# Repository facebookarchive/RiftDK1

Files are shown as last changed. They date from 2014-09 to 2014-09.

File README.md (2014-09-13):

Oculus Rift Development Kit 1
=======

Firmware, Schematics, and Mechanicals for the Oculus Rift Development Kit 1.

Firmware
--------

The Tracker firmware uses the CooCox CoIDE for development along with 
the gcc-arm-embedded toolchain.

The ST-Link/V2 is the cheapest way to load firmware onto a Tracker
board, though any SWD compatible programmer should work.  You can follow these steps
to set up a build environment and load firmware onto the board:

1. Install ST-Link drivers if you haven't: http://www.st.com/web/en/catalog/tools/PF258167
2. Install CoCenter: http://www.coocox.org/CooCox_CoIDE.htm
3. Through CoCenter, install CooCox and CoFlash
4. Install gcc-arm-embedded: https://launchpad.net/gcc-arm-embedded/+download
5. Set up gcc-arm-embedded in CooCox: http://www.coocox.org/CoIDE/Compiler_Settings.html
6. Clone our RiftDK1 repository to C:\CooCox\CoIDE\workspace
7. Open the Tracker.coproj
8. Build
9. Plug the ST-Link into the board's 10 pin SWD header.
10. Plug in USB to power the board.
12. Download code to Flash 
13. Enjoy!

Note that the USB Product ID is set to 0x0001, which matches the production
version of the Tracker.  If you modify the firmware in a way that
changes the USB interface, please change the Product ID to 0x0000.

Mechanical
----------

The Mechanical folder contains STEP files of the Rift DK1 housing, control box, and case.

Schematics
----------

The Schematics folder contains a pdf of the schematic, as well as Altium Designer files
of the schematic and board layout.

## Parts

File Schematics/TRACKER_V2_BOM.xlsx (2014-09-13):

Comment | Part Number | Description | Designator | Manufacturer | Quantity | Notes
4-103240-0-04 | 4-103240-0-04 | CONNECTOR, HEADER, 2X4, 0.1" PITCH | J4 | TE CONNECTIVITY | 1 | DNP
CSTCE8M00G55-R0 | CSTCE8M00G55-R0 | CERAMIC RESONATOR, 8MHz, +/-0.2%, 33pF, SMD | Y1 | MURATA ELECTRONICS | 1
22 ohm | ERJ-2RKF22R0X | RES, 22 OHM, 1/10W, ±1%, 0402 | R1, R2, R3, R4, R5, R7, R8, R9 | PANASONIC | 8
10K | ERJ-2RKF1002X | RES, 10K OHM, 1/10W, ±1%, 0402 | R6 | PANASONIC | 1
1.5K | ERJ-2RKF1501X | RES, 1.5K OHM, 1/10W, ±1%, 0402 | R10 | PANASONIC | 1
1uF | GRM155R61A105KE15D | CAP, CERAMIC, 1uF, ±10%, 10V, X5R, 0402 | C15 | MURATA ELECTRONICS | 1
0.1uF | GRM155R71C104KA88D | CAP, CERAMIC, 0.1uF, ±10%, 16V, X7R, 0402 | C5, C8, C11, C12, C13, C14, C16, C19, C21, C23 | MURATA ELECTRONICS | 10
0.22uF | GRM155R71C224KA12D | CAP, CERAMIC, 0.22uF, ±10%, 16V, X7R, 0402 | C17 | MURATA ELECTRONICS | 1
2200pF | GRM155R71H222KA01D | CAP, CERAMIC, 2200pF, ±10%, 50V, X7R, 0402 | C1, C2, C6, C7, C18 | MURATA ELECTRONICS | 5
10uF | GRM188R60J106ME47D | CAP, CERAMIC, 10uF, ±20%, 6.3V, X5R, 0603 | C3, C4, C9, C10, C20 | MURATA ELECTRONICS | 5
4.7uF | GRM188R60J475KE19D | CAP, CERAMIC, 4.7uF, ±10%, 6.3V, X5R, 0603 | C22 | MURATA ELECTRONICS | 1
GRPB052VWQP-RC | GRPB052VWQP-RC | CONNECTOR, 10 POS, ARM CORTEX SWD HEADER | J3 | SULLINS CONNECTOR | 1 | DNP
HMC5983 | HMC5983-TR | IC, MEMS 3 AXIS MAGNETOMETER | U4 | HONEYWELL | 1
LP5900SD-3.3 | LP5900SD-3.3/NOPB | IC, LINEAR REGULATOR, 3.3V, 150MA, ULTRA LOW NOISE | U2 | NATIONAL SEMICONDUCTOR | 1
MMZ1005S601C | MMZ1005S601C | FERRITE CHIP BEAD, 600 OHM @ 100MHz, 300mA, 0402 | L1, L2, L3, L4 | TDK CORPORATION | 4
MPU-6000 | MPU-6000 | IC, MEMS 3 AXIS GYROSCOPE AND 3 AXIS ACCELEROMETER | U3 | INVENSENSE | 1
STM32F103C8T6 | STM32F103C8T6 | IC, STM32 MICROCONTROLLER, ARM CORTEX M3 | U1 | ST MICROELECTRONICS | 1
USB_HEADER | TBD | CONNECTOR, HEADER, 4 POS | J1 | TBD | 1
ZX62-B-5PA(11) | ZX62-B-5PA(11) | CONNECTOR, USB MICRO B, R/A, SMD | J2 | HIROSE | 1 | DNP

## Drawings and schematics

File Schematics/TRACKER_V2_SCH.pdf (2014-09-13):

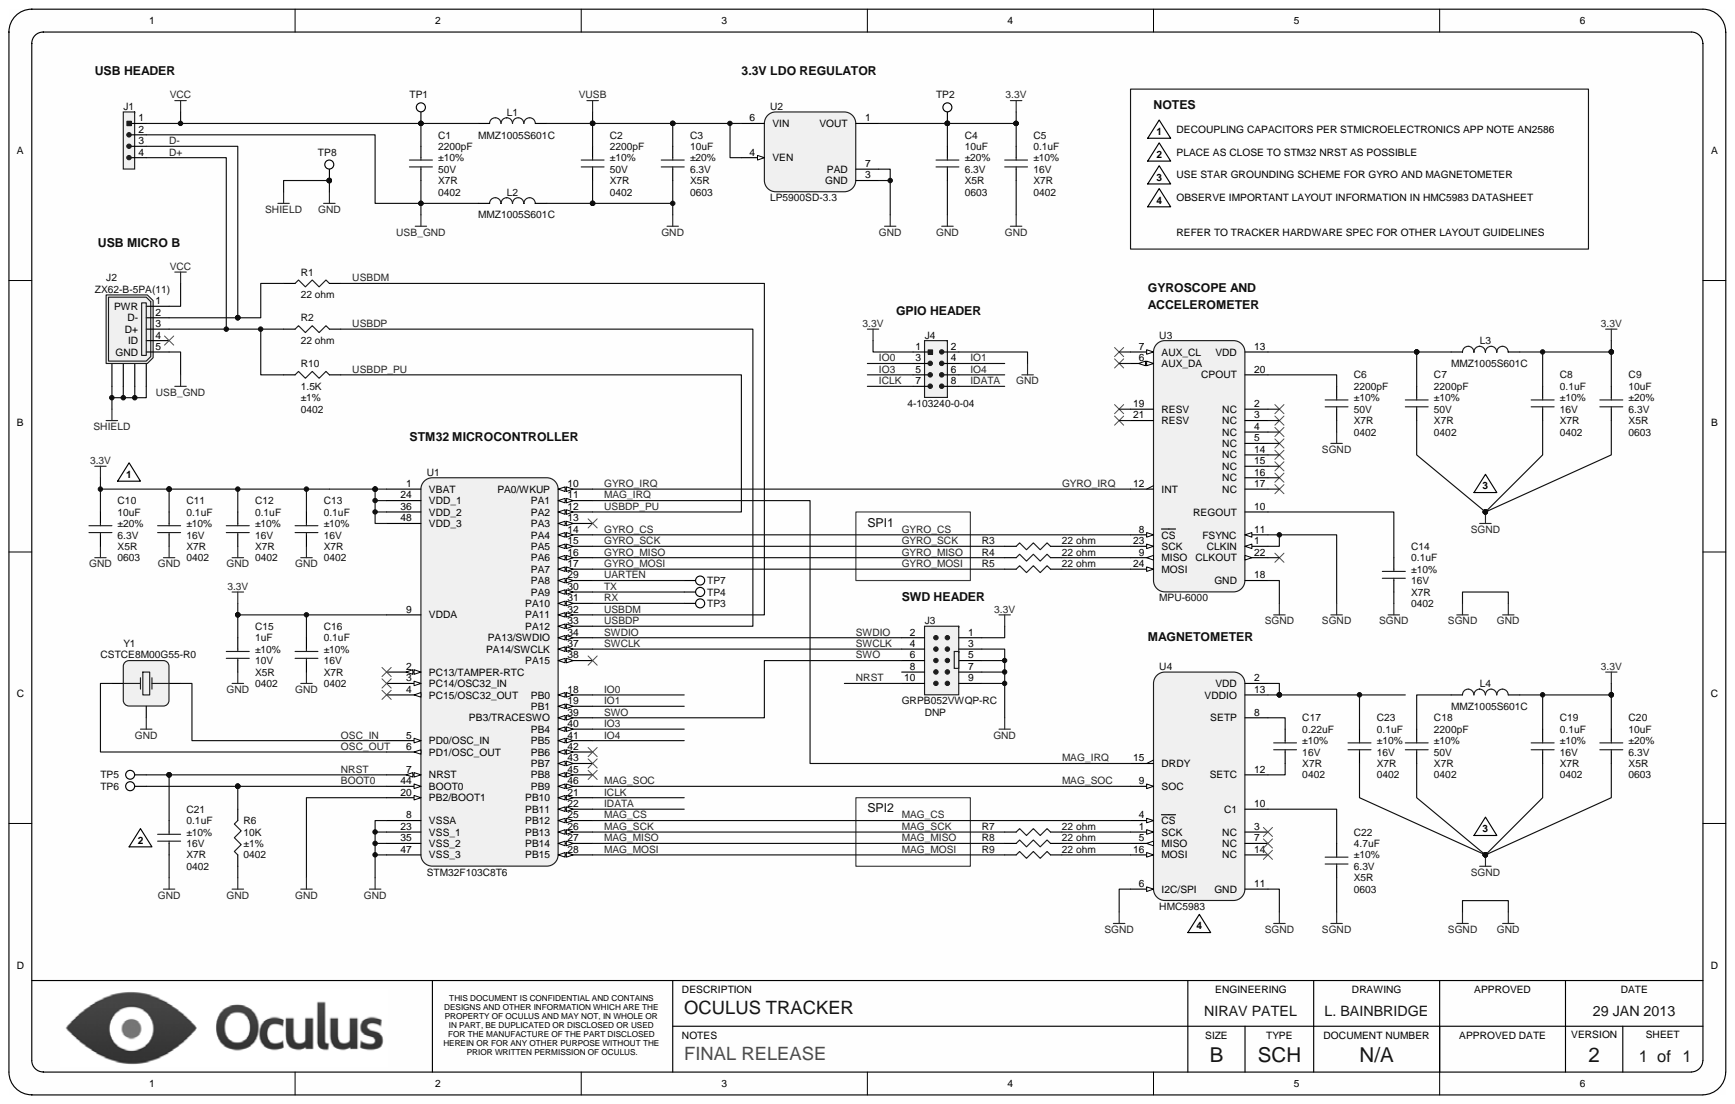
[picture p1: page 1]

1 DECOUPLING CAPACITORS PER STMICROELECTRONICS APP NOTE AN2586

2 PLACE AS CLOSE TO STM32 NRST AS POSSIBLE

3 USE STAR GROUNDING SCHEME FOR GYRO AND MAGNETOMETER

4 OBSERVE IMPORTANT LAYOUT INFORMATION IN HMC5983 DATASHEET

REFER TO TRACKER HARDWARE SPEC FOR OTHER LAYOUT GUIDELINES

THIS DOCUMENT IS CONFIDENTIAL AND CONTAINS
DESIGNS AND OTHER INFORMATION WHICH ARE THE
PROPERTY OF OCULUS AND MAY NOT, IN WHOLE OR
IN PART, BE DUPLICATED OR DISCLOSED OR USED
FOR THE MANUFACTURE OF THE PART DISCLOSED
HEREIN OR FOR ANY OTHER PURPOSE WITHOUT THE
PRIOR WRITTEN PERMISSION OF OCULUS.

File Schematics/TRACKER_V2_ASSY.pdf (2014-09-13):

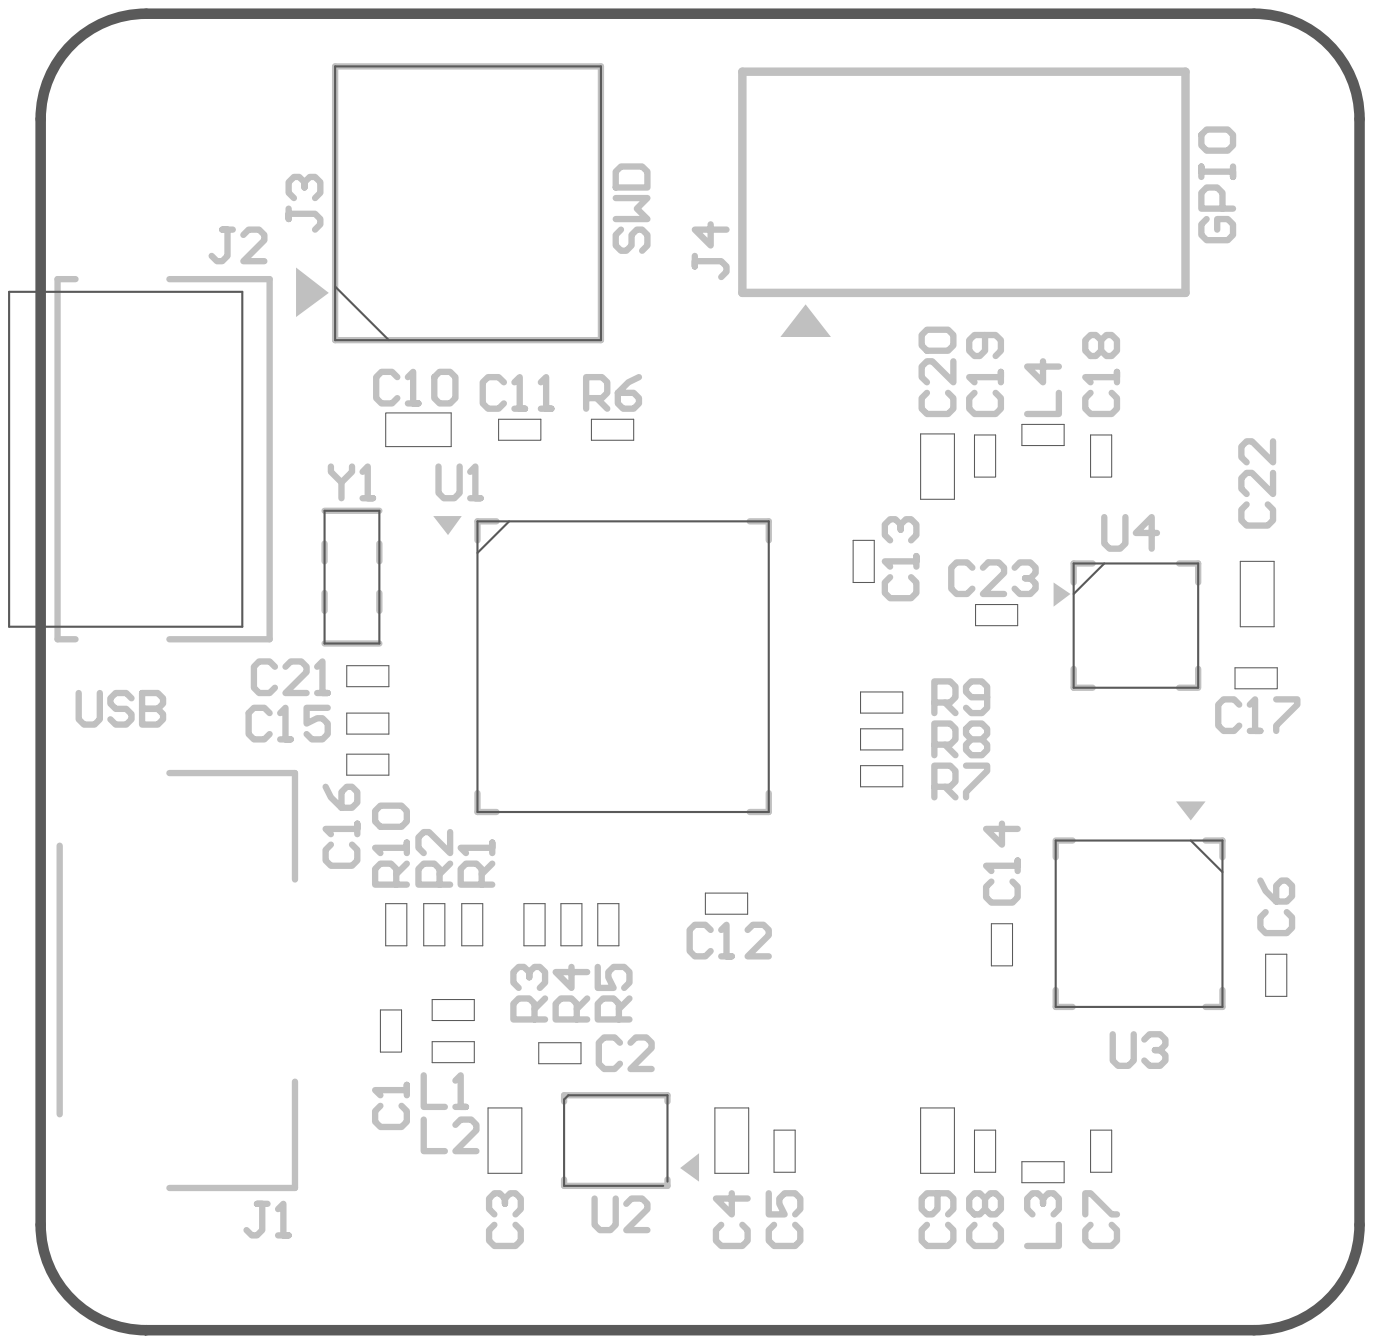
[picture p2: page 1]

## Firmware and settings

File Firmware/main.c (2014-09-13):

/************************************************************************************

Filename    :   main.c
Content     :   Main loop for Tracker
Created     :
Authors     :   Nirav Patel

Copyright   :   Copyright 2013 Oculus VR, Inc. All Rights reserved.

Use of this software is subject to the terms of the Oculus license
agreement provided at the time of installation or download, or which
otherwise accompanies this software in either electronic or hard copy form.

*************************************************************************************/

#include "hw_config.h"
#include "usb_lib.h"
#include "spi.h"
#include "invensense.h"
#include "hmc5983.h"
#include "delay.h"
#include "data_packet.h"
#include "feature_config.h"
#include "calibrate.h"
#include "autocalibrate.h"
#include "user_calibrate.h"
#include "factory.h"
#include "eeprom.h"
#include "eeprom_table.h"
#include "usb_pwr.h"
#include "uart.h"

static uint16_t last_command_id = 0;
static bool user_calibrating = 0;
static bool factory_calibrating = 0;
static feature_config_s config = {0};
static feature_calibrate_s calibrate = {0};
static feature_range_s range = {0};
static feature_register_s reg = {0};
static feature_dfu_s dfu = {0};
static feature_keep_alive_s keep_alive = {0};
static uart_s factory = {0};

// TODO: handle the count differently
__IO uint32_t int_count_inv = 0;
__IO uint32_t int_count_hmc = 0;
__IO uint8_t ep1_ready = 1;
__IO uint8_t exit_stop_mode = 1;

static inline void handle_feature_config()
{
    last_command_id = feature_config_latest_command_id();

    // Grab a feature config at the start so it doesn't change
    if (feature_config_get(&config)) {
        // dump partially stored packets when configuration changes
        data_packet_reset();

        // Handle the internal zero rate calibration process
        if (config.calibrate && !user_calibrating) {
            // start the calibration process
            user_calibrating = 1;
            user_calibrate_reset();
        } else if (user_calibrating && !config.calibrate) {
            // finish the calibration process
            user_calibrating = 0;
            user_calibrate_end();
        }
    }

    if (feature_calibrate_get(&calibrate)) {
        // dump partially stored packets when calibration changes
        data_packet_reset();
        calibrate_set(calibrate.payload);
    }

    if (feature_range_get(&range)) {
        // dump partially stored packets when the sensor ranges change
        data_packet_reset();
        invensense_set_ranges(range.accel_range, range.gyro_range);
        hmc_set_range(range.mag_range);
    }

    if (feature_register_get(&reg)) {
        switch (reg.device) {
            case FEATURE_REGISTER_INV:
                // dump partially stored packets only when gyro registers change
                data_packet_reset();
                invensense_set_register(reg.reg, reg.payload);
                break;

            case FEATURE_REGISTER_HMC:
                hmc_set_register(reg.reg, reg.payload);
                break;

            default:
                break;
        }
    }

    if (feature_dfu_get(&dfu)) {
        // Set the parameter in EEPROM so it can be read on boot
        FLASH_Unlock();
        EE_WriteVariable(EE_DFU_BOOT, dfu.use_dfu);
        FLASH_Lock();

        // Restart the device if we are told to
        if (dfu.use_dfu)
            Reset_Device();
    }

    // Just updates the interval used for keep_alive
    feature_keep_alive_get(&keep_alive);
}

int main(void)
{
    // Shut off JTAG and keep SWD on, needs to happen right after reset
    Configure_Debug();

    delay_init();
    // The MPU-6000 needs 100ms to stabilize before accessing registers
    // The HMC5983 needs 50ms to bring up its analog end
    delay_ms(100);

    // Initialize pins and interrupts
    Set_System();

    Enable_EXTInterrupts();

    // if the UARTEN pin is pulled high, it means we are in the factory
    // calibration rig
#ifdef UARTEN_PIN
    factory_calibrating = GPIO_ReadInputDataBit(UARTEN_PORT, UARTEN_PIN);
#endif /* UARTEN_PIN */

    // Set default configuration parameters
    // Default to 500 Hz
    config.interval = 1;
    // Default to command keep alive with a 10 second timeout
    config.command_keep_alive = 1;
    keep_alive.keep_alive = 10000;
    // Default to calibration on and automatic when not factory calibrating
    config.use_calibration = 1;
    config.autocalibration = 1;
    // Set the feature report versions to the default values
    feature_config_set(&config);
    feature_keep_alive_set(&keep_alive);

    // Get the sensors running
    Sensor_Init();

    // Load the calibration data from EEPROM
    calibrate_init();

    // Configure the USB hardware
    USB_Interrupts_Config();
    Set_USBClock();
    USB_Init();

    invensense_data_t inv_data = {0};
    hmc_data_t hmc_data = {{0}};
    uint32_t target = int_count_inv + 1;
    uint32_t last_hmc = 0;
    uint16_t timestamp = 0;
    // make this 16 bit to avoid wrapping before a chance to send occurs
    uint16_t interval_count = 0;
    uint32_t last_command_count = 0;

    if (factory_calibrating) {
        // Only enable UART if we are in the factory
#ifdef FACTORY_PORT
        uart_init(&factory, FACTORY_PORT, FACTORY_SPEED, FACTORY_GPIO_PORT, FACTORY_TX, FACTORY_RX);
        factory_set_interface(&factory);
#endif /* FACTORY_PORT */
    }

    while (1) {
        // A sort of primitive select() on the things we care to wake up for:
        // 0. If we are not suspended or resuming from suspend, and
        // 1. The gyro data ready interrupt has triggered
        // 2. USB got a suspend or resume event
        // 3. A Feature Report came in over USB
        // 4. If we are factory calibrating, a command came in over UART
        // Shut off the CPU clock while waiting
        while ((!exit_stop_mode &&
                !factory_calibrating &&
                (bDeviceState == SUSPENDED)) ||
               ((int_count_inv < target) &&
                !feature_config_got_command(1) &&
                (!factory_calibrating || !uart_available(&factory)))) {

            if ((bDeviceState == SUSPENDED) && !exit_stop_mode && !factory_calibrating) {
                Sensor_Sleep();
                // FIXME: Why doesn't resuming from STOP work?
                // Shut off all the clocks
                Enter_Stop();
                // Turn the clocks back on
                Wake_From_Stop();
                Sensor_Init();
                // Exiting USB Suspend mode due to Tracker motion
                if (exit_stop_mode == 2)
                    Resume(RESUME_INTERNAL);
            } else {
                __WFI();
            }
        }

        // Handle factory calibration commands
        if (factory_calibrating && uart_available(&factory)) {
            factory_set_command(uart_read(&factory));
        }

        // handle feature reports coming in
        if (feature_config_got_command(0)) {
            last_command_count = 0;
        }

        handle_feature_config();

        // Don't do any data reading if the gyro hasn't interrupted yet
        if (int_count_inv < target) continue;
        // Reached the interrupt target, so set the next one for 1ms away
        target++;

        // Read the sensors
        invensense_read(&inv_data, config.use_raw);
        timestamp = int_count_inv;
        // Only read the magnetometer on the first go or if it changed
        if (!last_hmc || (last_hmc != int_count_hmc)) {
            hmc_read(&hmc_data, config.use_raw);
            last_hmc = int_count_hmc;
        }

        // Manual, factory, and automatic calibration are mutually exclusive
        if (factory_calibrating)
            factory_update(&inv_data);
        else if (user_calibrating)
            user_calibrate_update(&inv_data);
        else
            autocalibrate_update(&inv_data, config.autocalibration);

        interval_count++;
        last_command_count++;

        // Only proceed with updating the packet if USB is enabled
        if (bDeviceState == CONFIGURED) {
            if (config.use_calibration) calibrate_apply(&inv_data);

            // Store the latest gyro/accel data
            data_packet_update(timestamp, &inv_data);

            // Load data into the hardware USB buffer if the conditions are met:
            // 1. Previous packet send completed
            // 2. If the device is configured to send on slower intervals, that interval has passed
            // 3. If motion keep alive is on, there has been motion within the last keep_alive.keep_alive milliseconds
            // 4. If command keep alive is on, there has been a feature report set within keep_alive.keep_alive milliseconds
            if (ep1_ready &&
                (interval_count > config.interval) &&
                (!config.motion_keep_alive || (autocalibrate_motion_count() <= keep_alive.keep_alive)) &&
                (!config.command_keep_alive || (last_command_count <= keep_alive.keep_alive))) {
                data_packet_generate(last_command_id, &hmc_data, config.use_ovr_coordinates);

                data_packet_send();
                ep1_ready = 0;
                interval_count = 0;
            }
        }
    }
}

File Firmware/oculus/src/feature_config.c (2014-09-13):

/************************************************************************************

Filename    :   feature_config.c
Content     :   Tracker feature reports
Created     :
Authors     :   Nirav Patel

Copyright   :   Copyright 2013 Oculus VR, Inc. All Rights reserved.

Use of this software is subject to the terms of the Oculus license
agreement provided at the time of installation or download, or which
otherwise accompanies this software in either electronic or hard copy form.

*************************************************************************************/

#include "feature_config.h"
#include <stdlib.h>
#include <string.h>
#include "platform_config.h"
#include "usb_core.h"
#include "usb_init.h"
#include "calibrate.h"
#include "invensense.h"
#include "hmc5983.h"
#include "eeprom.h"
#include "eeprom_table.h"
#include "gpio.h"

enum {
    FEATURE_CONFIG = 2,
    FEATURE_CALIBRATE = 3,
    FEATURE_RANGE = 4,
    FEATURE_REGISTER = 5,
    FEATURE_DFU = 6,
    FEATURE_GPIO = 7,
    FEATURE_KEEP_ALIVE = 8,
    FEATURE_DISPLAY_INFO = 9,
    FEATURE_SERIAL = 10
};

// Report ID and Command ID
#define FEATURE_HEADER_SIZE 3

#define FEATURE_CONFIG_SIZE (FEATURE_HEADER_SIZE+4)
#define FEATURE_CALIBRATE_SIZE (FEATURE_HEADER_SIZE+CALIBRATION_SIZE)
#define FEATURE_RANGE_SIZE (FEATURE_HEADER_SIZE+5)
#define FEATURE_REGISTER_SIZE (FEATURE_HEADER_SIZE+3)
#define FEATURE_DFU_SIZE (FEATURE_HEADER_SIZE+1)
#define FEATURE_GPIO_SIZE (FEATURE_HEADER_SIZE+2)
#define FEATURE_KEEP_ALIVE_SIZE (FEATURE_HEADER_SIZE+2)
#define FEATURE_DISPLAY_INFO_SIZE (FEATURE_HEADER_SIZE+53)
#define FEATURE_SERIAL_SIZE (FEATURE_HEADER_SIZE+12)

feature_config_s global_config = {0};
bool global_config_set = 0;
feature_calibrate_s global_calibrate = {0};
bool global_calibrate_set = 0;
feature_range_s global_range = {0};
bool global_range_set = 0;
feature_register_s global_reg = {0};
bool global_reg_set = 0;
feature_dfu_s global_dfu = {0};
bool global_dfu_set = 0;
feature_gpio_s global_gpio = {0};
feature_keep_alive_s global_keep_alive = {0};
bool global_keep_alive_set = 0;
feature_display_info_s global_display_info = {0};
feature_serial_s global_serial = {0};

// Most recent command ID globally
static uint16_t feature_config_command_id = 0;
bool got_command = 0;

// For the largest buffer we need
uint8_t feature_get_buf[FEATURE_CALIBRATE_SIZE];
uint8_t feature_set_buf[FEATURE_CALIBRATE_SIZE];

static void feature_config_pack_config(void)
{
    feature_get_buf[0] = FEATURE_CONFIG;
    *(uint16_t *)(feature_get_buf+1) = global_config.command_id;
    feature_get_buf[3] = global_config.use_raw |
                         (global_config.calibrate << 1) |
                         (global_config.use_calibration << 2) |
                         (global_config.autocalibration << 3) |
                         (global_config.motion_keep_alive << 4) |
                         (global_config.command_keep_alive << 5) |
                         (global_config.use_ovr_coordinates << 6);
    feature_get_buf[4] = global_config.interval;
    // For now, just hard code to 1000 Hz.  This is for forwards compatibility
    // with future trackers with different sample rates.
    *(uint16_t *)(feature_get_buf+5) = global_config.sample_rate = 1000;
}

static void feature_config_pack_range(void)
{
    feature_get_buf[0] = FEATURE_RANGE;
    *(uint16_t *)(feature_get_buf+1) = global_range.command_id;
    invensense_get_ranges(&global_range.accel_range, &global_range.gyro_range);
    feature_get_buf[3] = global_range.accel_range;
    *(uint16_t *)(feature_get_buf+4) = global_range.gyro_range;
    global_range.mag_range = hmc_get_range();
    *(uint16_t *)(feature_get_buf+6) = global_range.mag_range;
}

static void feature_config_pack_register(void)
{
    feature_get_buf[0] = FEATURE_REGISTER;
    *(uint16_t *)(feature_get_buf+1) = global_reg.command_id;
    feature_get_buf[3] = global_reg.device;
    feature_get_buf[4] = global_reg.reg;
    feature_get_buf[5] = global_reg.payload;
}
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

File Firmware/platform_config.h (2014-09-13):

/**
  ******************************************************************************
  * @file    platform_config.h
  * @author  MCD Application Team
  * @version V3.4.0
  * @date    29-June-2012
  * @brief   Evaluation board specific configuration file.
  ******************************************************************************
  * @attention
  *
  * <h2><center>&copy; COPYRIGHT 2012 STMicroelectronics</center></h2>
  *
  * Licensed under MCD-ST Liberty SW License Agreement V2, (the "License");
  * You may not use this file except in compliance with the License.
  * You may obtain a copy of the License at:
  *
  *        http://www.st.com/software_license_agreement_liberty_v2
  *
  * Unless required by applicable law or agreed to in writing, software
  * distributed under the License is distributed on an "AS IS" BASIS,
  * WITHOUT WARRANTIES OR CONDITIONS OF ANY KIND, either express or implied.
  * See the License for the specific language governing permissions and
  * limitations under the License.
  *
  ******************************************************************************
  */


/* Define to prevent recursive inclusion -------------------------------------*/
#ifndef __PLATFORM_CONFIG_H
#define __PLATFORM_CONFIG_H

#include "platform_common.h"

/* Includes ------------------------------------------------------------------*/

#if defined(STM32L1XX_MD) || defined(STM32L1XX_HD)|| defined(STM32L1XX_MD_PLUS)
 #include "stm32l1xx.h"
#elif defined (STM32F10X_MD) || defined (STM32F10X_HD) || defined (STM32F10X_XL) || defined (STM32F10X_CL)
 #include "stm32f10x.h"
#endif

/* Define the STM32F10x hardware depending on the used evaluation board */
#if defined (USE_STEVAL_MKI121V1)
  #define USB_DISCONNECT                      GPIOA
  #define USB_DISCONNECT_PIN                  GPIO_Pin_9
  #define RCC_APB2Periph_GPIO_DISCONNECT      RCC_APB2Periph_GPIOA

  #define LED_PORT                            GPIOA
  #define LED_PIN                             GPIO_Pin_1
  #define RCC_APB2Periph_GPIO_LED             RCC_APB2Periph_GPIOA

  #define INV_SPI                             SPI1
  #define INV_SPI_RCC                         RCC_APB2Periph_SPI1
// APB2 is running at full AHB, needs to be brought down to <= 1 MHz
  #define INV_SPI_SPEED_LOW                   SPI_BaudRatePrescaler_128
// Sensor registers can be read at up to 20 MHz
  #define INV_SPI_SPEED_HIGH                  SPI_BaudRatePrescaler_4
  #define INV_SPI_GPIO                        GPIOA
  #define INV_SPI_GPIO_RCC                    RCC_APB2Periph_GPIOA
  #define INV_SPI_SCK                         GPIO_Pin_5
  #define INV_SPI_MISO                        GPIO_Pin_6
  #define INV_SPI_MOSI                        GPIO_Pin_7
  #define INV_SPI_SS                          GPIO_Pin_4
  #define INV_INT                             GPIO_Pin_0
  #define INV_INT_LINE                        EXTI_Line0
  #define INV_INT_PORT_SOURCE                 GPIO_PortSourceGPIOA
  #define INV_INT_PIN_SOURCE                  GPIO_PinSource0
  #define INV_INT_IRQn                        EXTI0_IRQn

// note that this dev board only has one SPI port exposed
  #define HMC_SPI                             SPI1
  #define HMC_SPI_RCC                         RCC_APB2Periph_SPI1
// APB2 is running at full AHB, needs to be brought down to <= 8 MHz
  #define HMC_SPI_SPEED                       SPI_BaudRatePrescaler_16
  #define HMC_SPI_GPIO                        GPIOA
  #define HMC_SPI_GPIO_RCC                    RCC_APB2Periph_GPIOA
  #define HMC_SPI_SCK                         GPIO_Pin_5
  #define HMC_SPI_MISO                        GPIO_Pin_6
  #define HMC_SPI_MOSI                        GPIO_Pin_7
  #define HMC_SPI_SS                          GPIO_Pin_2
  #define HMC_INT                             GPIO_Pin_3
  #define HMC_INT_LINE                        EXTI_Line3
  #define HMC_INT_PORT_SOURCE                 GPIO_PortSourceGPIOA
  #define HMC_INT_PIN_SOURCE                  GPIO_PinSource3
  #define HMC_INT_IRQn                        EXTI3_IRQn

// There is an onboard gyro on this board
  #define L3G_SPI                             SPI2
  #define L3G_SPI_RCC                         RCC_APB1Periph_SPI2
  // APB2 runs at 36 MHz, needs to be brought below 10
  #define L3G_SPI_SPEED                       SPI_BaudRatePrescaler_4
  #define L3G_SPI_GPIO                        GPIOB
  #define L3G_SPI_GPIO_RCC                    RCC_APB2Periph_GPIOB
  #define L3G_SPI_SCK                         GPIO_Pin_13
  #define L3G_SPI_MISO                        GPIO_Pin_14
  #define L3G_SPI_MOSI                        GPIO_Pin_15
  #define L3G_SPI_SS                          GPIO_Pin_12
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

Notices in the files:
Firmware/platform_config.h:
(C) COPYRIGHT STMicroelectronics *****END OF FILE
